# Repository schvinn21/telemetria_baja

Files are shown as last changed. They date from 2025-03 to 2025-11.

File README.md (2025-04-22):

# 📡 Projeto de Telemetria CAN com ESP32

Este projeto realiza a leitura de dados do acelerômetro MPU6050 e do módulo GPS NEO-M8N, transmitindo-os via protocolo CAN utilizando dois ESP32 e módulos com CI SN65HVD230. O objetivo é facilitar a coleta de dados em tempo real em ambientes como veículos off-road (ex: Baja SAE).

---

## 📁 Estrutura de Diretórios Recomendada

```bash
project-name/
├── CMakeLists.txt
├── sdkconfig
├── sdkconfig.defaults
├── main/
│   ├── main.c
│   └── CMakeLists.txt
├── components/
│   ├── mpu6050/
│   │   ├── mpu6050.c
│   │   ├── mpu6050.h
│   │   └── CMakeLists.txt
│   ├── gps/
│   │   ├── gps.c
│   │   ├── gps.h
│   │   └── CMakeLists.txt
│   └── can_transmiter/
│       ├── can_transmiter.c
│       ├── can_transmiter.h
│       └── CMakeLists.txt
├── .gitignore
└── README.md
```

> ❗ **Atenção:** A pasta `build/` gerada na compilação não deve ser versionada. Certifique-se de incluí-la no `.gitignore`.

---

## 💻 Requisitos para Execução

### 🧰 Instalações Necessárias

1. [ESP-IDF](https://docs.espressif.com/projects/esp-idf/en/latest/esp32/get-started/index.html)
2. Python 3 (recomendado usar virtualenv)
3. Dependências via pip:
   ```bash
   pip install esptool pyserial
   ```

### 📦 Drivers (Windows)

- Driver USB-to-Serial para ESP32 (CH340 ou CP2102)

---

## 🛠️ Como Compilar e Rodar

1. Configure o ambiente:
   ```bash
   . $HOME/esp/esp-idf/export.sh
   ```

2. Navegue até o diretório do projeto:
   ```bash
   cd project-name
   ```

3. Compile e carregue:
   ```bash
   idf.py build
   idf.py -p /dev/ttyUSB0 flash monitor
   ```

---

## 🚐 Funcionamento da Comunicação CAN

A rede CAN (Controller Area Network) é utilizada para comunicação entre microcontroladores, permitindo troca de dados em tempo real, com alta confiabilidade e resistência a ruído.

### ✅ Características:

- Comunicação serial diferencial (alta imunidade a interferências)
- Taxa usada: **500 kbps**
- Até **8 bytes por frame CAN**
- Prioridade de mensagens baseada no ID (menor ID = maior prioridade)

### 🔧 Aplicação neste Projeto:

Dois ESP32 comunicam-se via CAN:

- O **Transmissor** envia dados do MPU6050 e GPS usando dois frames:
  - `ID 0x123`: Aceleração X, Y, Z
  - `ID 0x124`: Latitude e Longitude (tipo `float`, codificados em IEEE 754)

- O **Receptor** decodifica os frames recebidos e imprime os valores no terminal.

> ⚠️ Os módulos CAN (SN65HVD230) devem ser ligados com resistores de terminação de 120 Ω entre CAN_H e CAN_L.

---

## 📌 Observações

- O GPS deve estar em ambiente aberto para obter sinal.
- Certifique-se de alimentar corretamente os módulos. O GPS e o CAN podem exigir corrente acima de 100 mA.
- Evite subir arquivos como `build/` e `.pioenvs/` ao repositório. Use `.gitignore` corretamente.

---

## 📷 Exemplo de Saída

```
Accel X: -520, Y: 256, Z: 16234
Latitude: -30.0457
Longitude: -51.2309
```

---

## 📍 Próximos Passos

- Envio dos dados via rede GSM (SIM900A)
- Visualização em dashboard web
- Armazenamento local (SD Card) ou remoto (MQTT, REST API)

---

Desenvolvido por **Eduardo Schvinn**  
Projeto para aplicação em competições **Baja SAE** 🏁

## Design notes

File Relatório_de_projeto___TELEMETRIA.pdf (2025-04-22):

# Documentação do Projeto de Telemetria CAN com ESP32

### Eduardo Schvinn

### April 22, 2025

## 1 Introdução

Este projeto tem como objetivo transmitir dados de sensores (aceleração e GPS) via protocolo CAN utilizando ESP32. A proposta visa facilitar a coleta de dados em tempo real para aplicações como monitoramento veicular em protótipos Baja SAE.

## 2 Componentes Utilizados

- 2 x ESP32 (ESP-IDF)
- 1 x Módulo MPU6050 (Acelerômetro e Giroscópio)
- 1 x Módulo GPS NEO-M8N
- 2 x Módulo CAN com CI SN65HVD230
- Cabos, protoboards e fonte de alimentação

## 3 Funcionamento Geral

- O ESP transmissor coleta dados do MPU6050 e do GPS.
- As informações são organizadas em pacotes CAN com identificadores 0x123 (aceleração) e 0x124 (GPS).
- O ESP receptor interpreta os pacotes e exibe os dados no terminal.

## 4 Estrutura dos Frames CAN Transmitidos

O sistema transmite dois frames distintos na rede CAN, cada um com identificador e estrutura de payload definidos:

### Frame 1: Dados de Aceleração (ID 0x123)

- 6 bytes no total.
- Cada componente da aceleração (X, Y, Z) codificado em dois bytes (int16 t).
- Formato big-endian:

[ ax H, ax L, ay H, ay L, az H, az L ]

- Exemplo:

– ax = -512 0xFE00, ay = 256 0x0100, az = 16383 0x3FFF

– Payload: FE 00 01 00 3F FF

### Frame 2: Coordenadas GPS (ID 0x124)

- 8 bytes no total.
- Latitude e longitude como float (IEEE 754), 4 bytes cada.
- Formato little-endian:

[ latitude (4B), longitude (4B) ]

- Exemplo:

– Latitude = -30.0457, Longitude = -51.2309

– Representação: 9A 99 F0 C1 0B 8D 4E C2

### Resumo dos Frames

Frame | ID | Bytes (Payload) | Conteúdo
Frame 1 Frame 2 | 0x123 0x124 | 6 8 | Aceleração (X, Y, Z) Latitude (4B) + Longitude (4B)

## 5 Formato dos Dados Transmitidos

A separação em dois frames evita a perda de precisão das coordenadas GPS. Frame 1 (ID 0x123):

- Bytes 0-1: aceleração em X (int16)
- Bytes 2-3: aceleração em Y (int16)
- Bytes 4-5: aceleração em Z (int16)

Frame 2 (ID 0x124):

- Bytes 0-3: latitude (float)
- Bytes 4-7: longitude (float)

## 6 Conversão de Dados GPS no Receptor

A transmissão das coordenadas GPS segue o padrão IEEE 754 para float (4 bytes), utilizando a ordem little-endian.

### No Transmissor

Os valores são copiados diretamente para o buffer da mensagem:

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

### No Receptor

O processo reverso reconstitui os valores:

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

### Considerações

- A ordem dos bytes deve ser idêntica em ambos os dispositivos.
- O uso de memcpy garante fidelidade dos dados sem conversões.
- O formato binário permite transmitir floats com eficiência.

## 7 Fluxo do Sistema

1. Inicialização de UART (GPS), I2C (MPU6050) e CAN.
2. Leitura dos sensores.
3. Transmissão a cada 500ms.
4. Receptor interpreta e exibe os dados no terminal.

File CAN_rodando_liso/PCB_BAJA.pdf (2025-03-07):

1 | Placas de Circuito Impresso – CTJ Baja

SENSOR DE TEMPERATURA

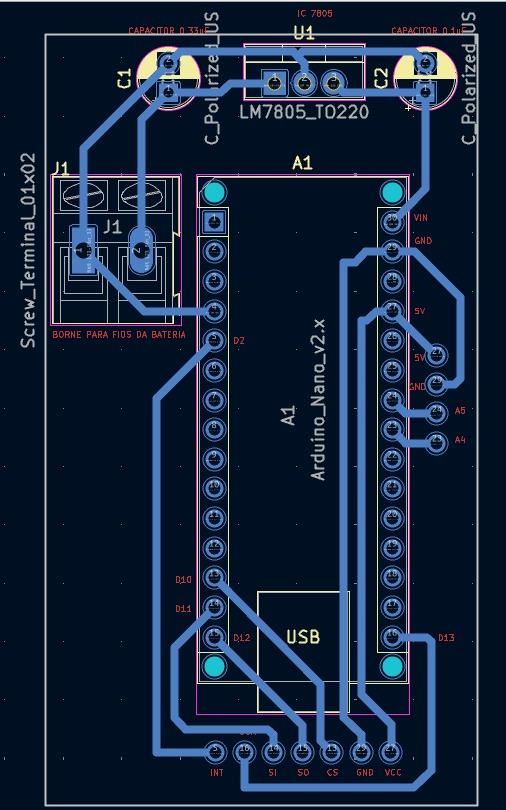
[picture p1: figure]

COMPONENTES

- Arduino nano;
- Dois capacitores;
- Um regulador de tensão LM7805;
- Módulo CAN MCP2515;
- Sensor de temperatura mlx90614

PINAGEM

1. Módulo CAN → Arduino Nano
- Int → D2
- SCK →D13
- SI → D11
- SO → D12
- CS → D10
- GND → GND
- VCC → 5V
2. Sensor temp. → Arduino nano
- VIN →5V
- GND → GND
- SCL → A5
- SDA → A4

SENSOR DE COMBUSTÍVEL

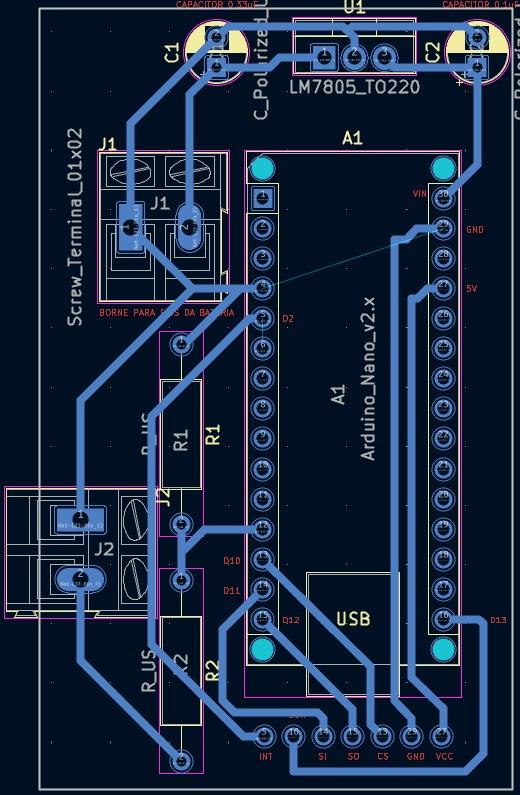
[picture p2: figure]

COMPONENTES

- Arduino nano;
- Dois capacitores;
- Um regulador de tensão LM7805;
- Módulo CAN MCP2515;
- Divisor de tensão (dois resistores);
- Sensor de combustível.

PINAGEM

1. Módulo CAN → Arduino Nano
- Int → D2
- SCK →D13
- SI → D11
- SO → D12
- CS → D10
- GND → GND
- VCC → 5V
2. Sensor combustível → Arduino nano
- Sinal → R2 → D9 → R1

R1 → GND

- GND → GND

SENSOR DE VELOCIDADE

COMPONENTES

- Arduino nano;

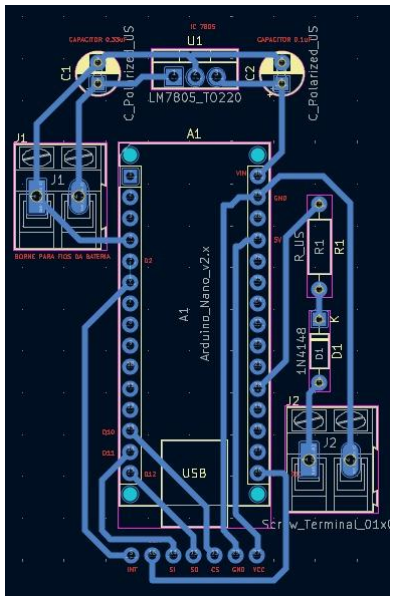
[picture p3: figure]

- Dois capacitores;
- Um regulador de tensão LM7805;
- Módulo CAN MCP2515;
- Resistor;
- Diodo;
- Sensor de velocidade;

PINAGEM

1. Módulo CAN → Arduino Nano
- Int → D2
- SCK →D13
- SI → D11
- SO → D12
- CS → D10
- GND → GND
- VCC → 5V
2. Sensor de Velocidade → Arduino nano
- GND → GND
- Sinal → diodo → resistor → A1

ESP32

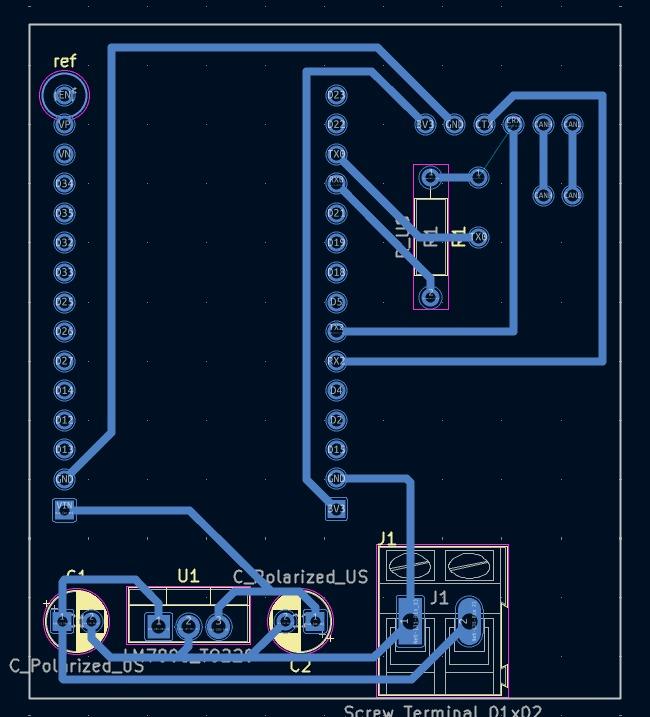
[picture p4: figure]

COMPONENTES

- ESP32;
- Dois capacitores;
- Um regulador de tensão LM7805;
- Módulo CAN bus SN65HVD230;
- Resistor.

PINAGEM

1. Módulo CAN → ESP32
- 3V3 → 3V3
- GND →GND
- CTX → RX2
- CRX → TX2
- CANH → CANH
- CANL → CANL
2. ESP32 COMUNICAÇÃO → UART
- RX0 → resistor → TX1 (Arduino)
- TX0 → RX0 (Arduino)

PAINEL

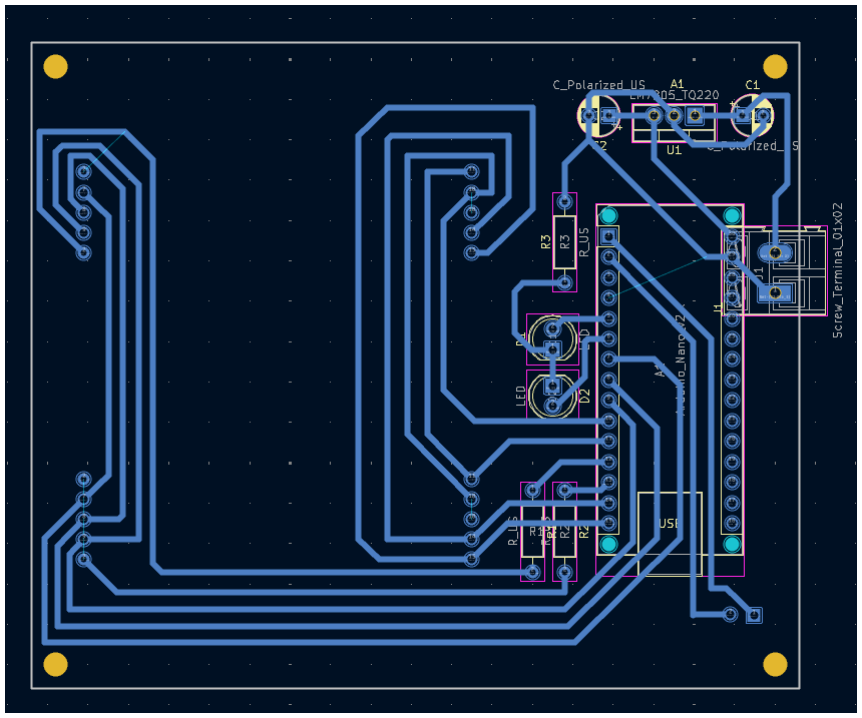
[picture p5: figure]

COMPONENTES

- Arduino nano;
- Dois capacitores;
- Um regulador de tensão LM7805;
- Três resistores;
- Dois displays de 7 segmentos, cátodo comum, FJS18101AH;
- Dois LEDs;
- Dois furos para comunicação UART;

PINAGEM

Os dois displays estão com todos os pinos conectados, exceto os pinos 1, 5 e 8

1. Displays → Arduino
- Disp.(1) 5 → Resistor 1 → D9
- Disp.(2) 5 → Resistor 2 → D10
- 7 → D11 > A
- 6 → D12 > B
- 4 → D6 > C
- 3 → D5 > D
- 2 → D4 > E
- 9 → D7 > F
- 10 → D8 > G
- 8 → Não está conectado > DP
2. LEDs → Arduino
- LED(1) → D2
- GND → GND led(2) → resistor → GND
- LED(2) → D3
- GND → GND led(1) → resistor → GND
3. Comunicação UART_ESP32 → Arduino
- RX0 → TX1
- TX0 → resistor(esp32) → RX0

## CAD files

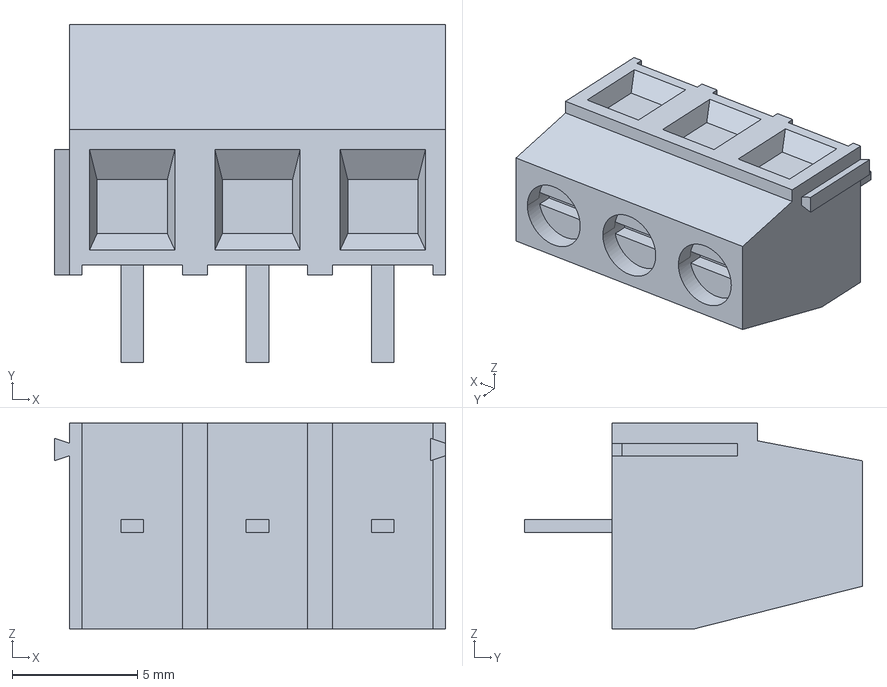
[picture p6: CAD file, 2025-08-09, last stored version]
pcb_telemetria/componentes/282836-3/282836-3.step
15.6 x 13.5 x 8.20 mm

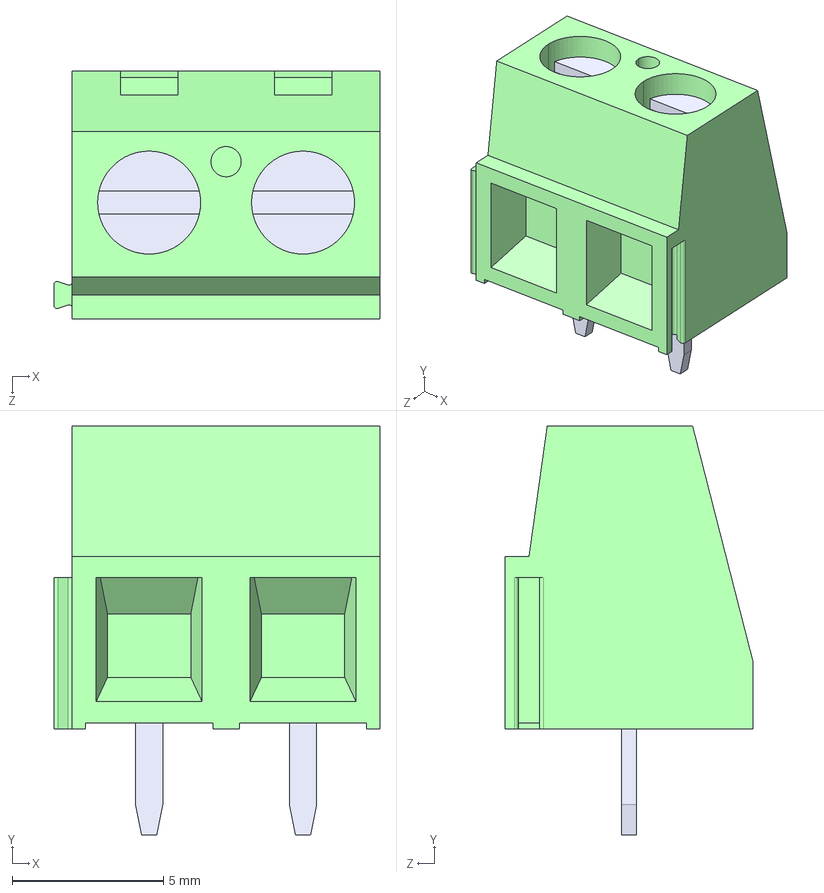
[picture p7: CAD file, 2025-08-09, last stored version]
pcb_telemetria/componentes/282837-2/282837-2.step
10.8 x 13.5 x 8.20 mm

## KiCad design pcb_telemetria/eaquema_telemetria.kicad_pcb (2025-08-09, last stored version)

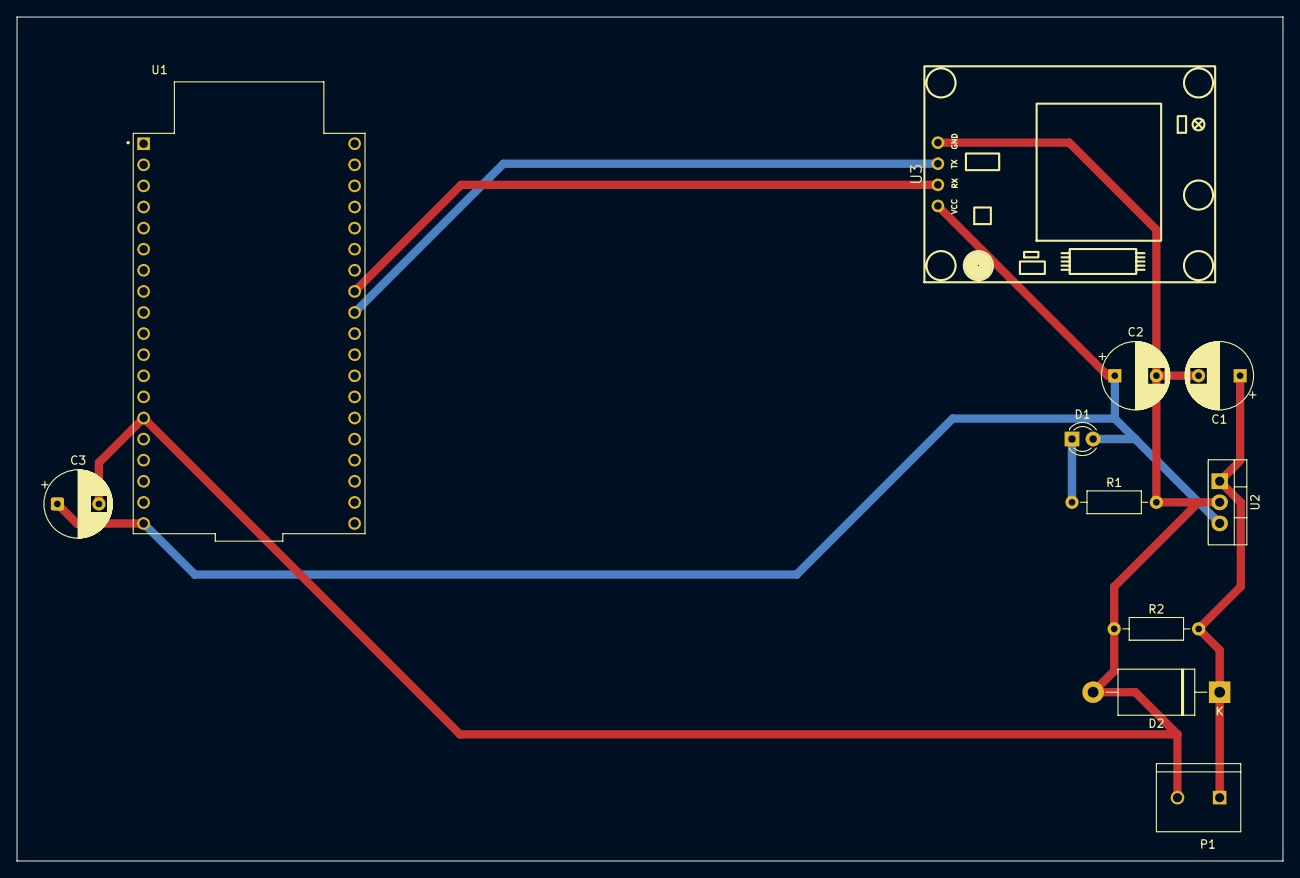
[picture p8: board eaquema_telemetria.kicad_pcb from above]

Board: 2 copper layers, 152.4 x 101.6 mm, 11 parts (0 on the bottom side), 6 nets.

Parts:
C1: 220uF; CP_Radial_D8.0mm_P5.00mm
C2, C3: 10nF; CP_Radial_D8.0mm_P5.00mm
D1: LED; LED_D3.0mm
D2: 1N4742; D_DO-201AE_P15.24mm_Horizontal
P1: kre; TE_282837-2
R1: 220; R_Axial_DIN0207_L6.3mm_D2.5mm_P10.16mm_Horizontal
R2: 2.2; R_Axial_DIN0207_L6.3mm_D2.5mm_P10.16mm_Horizontal
U1: ESP32-DEVKITC; MODULE_ESP32-DEVKITC
U2: LM7805_TO220; TO-220-3_Vertical
U3: NEO6MV2; NEO-6M-V2-GPSMODULE-FOOTPRINT

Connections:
+5V: C2.1, C3.1, D1.2 (A), U1.19 (EXT_5V), U2.3 (VO), U3.1 (VCC)
+12V: C1.1, D2.1 (A1), P1.1, R2.2, U2.1 (VI)
GND: C1.2, C2.2, C3.2, D2.2 (A2), P1.2, R1.2, R2.1, U1.14 (GND1), U2.2 (GND), U3.4 (GND)
unnamed: D1.1 (K), R1.1
RX: U1.31 (IO19), U3.2 (RX)
TX: U1.30 (IO18), U3.3 (TX)

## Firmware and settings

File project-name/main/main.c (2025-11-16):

// #include <stdio.h>
// #include <inttypes.h>              // PRIu32
// #include "freertos/FreeRTOS.h"
// #include "freertos/task.h"
// #include "esp_log.h"

// #include "sensor_temp.h"           // driver DS18B20
// #include "sensor_fluxo.h"          // driver de fluxo
// #include "can_transmiter.h"        // seu driver CAN

// static const char *TAG = "app_main";

// // Pinos escolhidos
// #define DS18_PIN    GPIO_NUM_4     // DS18B20 no GPIO4
// #define FLUXO_PIN   GPIO_NUM_14    // Sensor de fluxo no GPIO14

// void app_main(void)
// {
//     esp_err_t err;

//     vTaskDelay(pdMS_TO_TICKS(100));   // pequena estabilização

//     // ---------- LOG DO DRIVER GPIO MAIS BAIXO (pra não poluir serial) ----------
//     esp_log_level_set("gpio", ESP_LOG_WARN);

//     // ---------- CONFIG DS18B20 ----------
//     ds18b20_t temp1;

//     err = ds18b20_init(&temp1, DS18_PIN, false);   // VDD em 3V3, sem modo parasita
//     if (err != ESP_OK) {
//         ESP_LOGE(TAG, "DS18B20 init falhou: %s", esp_err_to_name(err));
//         return;
//     }

//     (void) ds18b20_set_resolution(&temp1, 12);     // 12 bits (~750 ms conversão)

//     // ---------- CONFIG FLUXO ----------
//     sensor_fluxo_config_t cfg = {
//         .pin               = FLUXO_PIN,
//         .pulses_per_liter  = 450.0f,   // ajusta pro seu sensor
//         .sample_ms         = 1000,     // janela de cálculo (ms)
//         .glitch_us         = 100,      // anti-ruído (us)
//         .use_internal_pullup = true    // ideal ter pull-up externo de 10k em 3V3 também
//     };

//     err = sensor_fluxo_init(&cfg);
//     if (err != ESP_OK) {
//         ESP_LOGE(TAG, "sensor_fluxo_init falhou: %s", esp_err_to_name(err));
//         return;
//     }

//     // ---------- CONFIG CAN ----------
//     err = can_transmiter_init();
//     if (err != ESP_OK) {
//         ESP_LOGE(TAG, "CAN init falhou: %s", esp_err_to_name(err));
//         return;
//     }

//     ESP_LOGI(TAG, "Sistema iniciado: CSV pela serial + envio via CAN...");

//     // --------- CABEÇALHO CSV (uma vez só) ---------
//     // Formato: temp_c;flow_l_min;total_liters;pulses_window
//     printf("temp_c;flow_l_min;total_liters;pulses_window\r\n");
//     fflush(stdout);

//     while (1) {
//         float t1 = 0.0f;
//         sensor_fluxo_metrics_t m = (sensor_fluxo_metrics_t){0};

//         // --------- TEMPERATURA ---------
//         if (ds18b20_read_celsius(&temp1, &t1) != ESP_OK) {
//             ESP_LOGW(TAG, "falha ao ler temp1");
//             t1 = -999.0f;  // marca erro no CSV
//         }

//         // --------- FLUXO ---------
//         sensor_fluxo_get_metrics(&m);
// dgbd
//         // --------- LINHA CSV PARA PYTHON ---------
//         printf("%.2f;%.3f;%.3f;%" PRIu32 "\r\n",
//                t1,
//                (double)m.flow_l_min,
//                (double)m.total_liters,
//                m.pulses_window);
//         fflush(stdout);

//         // --------- ENVIO POR CAN ---------
//         // temp2 por enquanto = temp1 (até você ligar um segundo DS18)
//         float temp2 = t1;
//         err = can_enviar_temp_e_total_compacto(t1, temp2, m.total_liters);
//         if (err != ESP_OK) {
//             ESP_LOGW(TAG, "Falha ao enviar quadro CAN");
//         }

//         // Log básico local
//         ESP_LOGI(TAG, "T=%.2f °C | flow=%.3f L/min | total=%.3f L",
//                  t1, (double)m.flow_l_min, (double)m.total_liters);

//         vTaskDelay(pdMS_TO_TICKS(1000));  // 1 amostra / frame por segundo
//     }
// }




// #include <stdio.h>
// #include <inttypes.h>              // PRIu32
// #include "freertos/FreeRTOS.h"
// #include "freertos/task.h"
// #include "esp_log.h"

// #include "sensor_temp.h"           // driver DS18B20
// #include "sensor_fluxo.h"          // driver de fluxo

// static const char *TAG = "app_main";

// // Pinos escolhidos
// #define DS18_PIN    GPIO_NUM_4     // DS18B20 no GPIO4
// #define FLUXO_PIN   GPIO_NUM_14    // Sensor de fluxo no GPIO14

// void app_main(void)
// {
//     esp_err_t err;

//     vTaskDelay(pdMS_TO_TICKS(100));   // pequena estabilização

//     // ---------- CONFIG DS18B20 ----------
//     ds18b20_t temp1;

//     err = ds18b20_init(&temp1, DS18_PIN, false);   // VDD em 3V3, sem modo parasita
//     if (err != ESP_OK) {
//         ESP_LOGE(TAG, "DS18B20 init falhou: %s", esp_err_to_name(err));
//         return;
//     }

//     (void) ds18b20_set_resolution(&temp1, 12);     // 12 bits (~750 ms conversão)

//     // ---------- CONFIG FLUXO (igual teu exemplo) ----------
//     sensor_fluxo_config_t cfg = {
//         .pin               = FLUXO_PIN,
//         .pulses_per_liter  = 450.0f,   // ajusta pro seu sensor
//         .sample_ms         = 1000,     // janela de cálculo (ms)
//         .glitch_us         = 100,      // anti-ruído (us)
//         .use_internal_pullup = true    // ideal ter pull-up externo de 10k em 3V3 também
//     };

//     err = sensor_fluxo_init(&cfg);
//     if (err != ESP_OK) {
//         ESP_LOGE(TAG, "sensor_fluxo_init falhou: %s", esp_err_to_name(err));
//         return;
//     }

//     ESP_LOGI(TAG, "Sistema iniciado: lendo temperatura (GPIO4) e fluxo (GPIO14)...");

//     while (1) {
//         float t1 = 0.0f;
//         sensor_fluxo_metrics_t m = {0};

//         // --------- TEMPERATURA ---------
//         if (ds18b20_read_celsius(&temp1, &t1) != ESP_OK) {
//             ESP_LOGW(TAG, "falha ao ler temp1");
//         }

//         // --------- FLUXO ---------
//         sensor_fluxo_get_metrics(&m);

//         ESP_LOGI(TAG,
//                  "T=%.2f °C | pulses=%" PRIu32 " | flow=%.3f L/min | total=%.3f L",
//                  t1,
//                  m.pulses_window,
//                  (double)m.flow_l_min,
//                  (double)m.total_liters);

//         vTaskDelay(pdMS_TO_TICKS(1000));
//     }
// }


#include <stdio.h>
#include <inttypes.h>
#include "freertos/FreeRTOS.h"
#include "freertos/task.h"
#include "rotacao.h"
#include "esp_log.h"
#include "esp_err.h"

static const char *TAG = "app";

// === Ajustes do projeto ===
#define RPM_PIN             GPIO_NUM_27   // escolha um GPIO "seguro" para entrada
#define PULSES_PER_REV      2             // nº de pulsos por volta mecânica
#define MIN_PULSE_US        500        // anti-ruído: rejeita bordas mais rápidas que isso
#define SAMPLE_WINDOW_MS    1000          // janela de amostragem p/ cálculo de RPM

// === Parâmetros do filtro exponencial ===
#define RPM_FILTER_ALPHA    0.20f         // 0.1 = mais suave; 0.5 = mais responsivo

void rpm_task(void *arg)
{
    rpm_counter_t *rc = (rpm_counter_t*)arg;

    // estado do filtro
    static float rpm_filt = 0.0f;
    static bool  filt_init = false;

    ESP_LOGI(TAG, "rpm_task iniciada, janela=%d ms, pulses/rev=%u",
             SAMPLE_WINDOW_MS, rc->cfg.pulses_per_rev);

    while (1) {
        vTaskDelay(pdMS_TO_TICKS(SAMPLE_WINDOW_MS));

        uint32_t pulses = rpm_counter_read_and_reset(rc);
        uint32_t rpm    = rpm_counter_to_rpm(pulses, SAMPLE_WINDOW_MS,
                                             rc->cfg.pulses_per_rev);

        // inicializa filtro com primeira medida
        if (!filt_init) {
            rpm_filt = (float)rpm;
            filt_init = true;
        } else {
            rpm_filt = RPM_FILTER_ALPHA * (float)rpm
                     + (1.0f - RPM_FILTER_ALPHA) * rpm_filt;
        }

        // 1) Linha "limpa" para o Python: RAW;FILT
        //    Ex.: 1234;1180.5
        printf("%" PRIu32 ";%.1f\n", rpm, (double)rpm_filt);

        // 2) Log informativo no monitor
        ESP_LOGI(TAG, "RPM raw=%" PRIu32 " | RPM filt=%.1f (pulses=%" PRIu32 ")",
                 rpm, (double)rpm_filt, pulses);
    }
}

void app_main(void)
{
    ESP_LOGI(TAG, "Iniciando leitura de RPM...");

    rpm_counter_t rc;
    rpm_counter_cfg_t cfg = {
        .pin            = RPM_PIN,
        .pulses_per_rev = PULSES_PER_REV,
        .min_pulse_us   = MIN_PULSE_US,
        .pullup         = true,     // habilita PULLUP interno
        .rising_edge    = true
    };

    esp_err_t err = rpm_counter_init(&rc, &cfg);
    if (err != ESP_OK) {
        ESP_LOGE(TAG, "Falha em rpm_counter_init(): %s", esp_err_to_name(err));
        return;
    }
    ESP_LOGI(TAG, "rpm_counter_init OK");

    err = rpm_counter_start(&rc);
    if (err != ESP_OK) {
        ESP_LOGE(TAG, "Falha em rpm_counter_start(): %s", esp_err_to_name(err));
        return;
    }
    ESP_LOGI(TAG, "rpm_counter_start OK");

    if (xTaskCreatePinnedToCore(rpm_task,
                                "rpm_task",
                                4096,      // mais stack pra garantir
                                &rc,
                                5,
                                NULL,
                                tskNO_AFFINITY) != pdPASS) {
        ESP_LOGE(TAG, "Falha ao criar tarefa RPM");
        return;
    }

    ESP_LOGI(TAG, "Tarefa RPM criada com sucesso");
    // app_main pode retornar; rpm_task continua rodando
}

// #include <stdio.h>
// #include "freertos/FreeRTOS.h"
// #include "freertos/task.h"
// #include "esp_log.h"

// #include "sensor_temp.h"       // DS18B20
// #include "sensor_fluxo.h"      // teu driver já funcional
// #include "can_transmiter.h"    // abaixo

// #define TAG "APP"

// // dois sensores de temp
// #define DS18_PIN_1  GPIO_NUM_33
// #define DS18_PIN_2  GPIO_NUM_32
// void app_main(void)
// {
//     esp_err_t err;

//     vTaskDelay(pdMS_TO_TICKS(100));

//     // ---------- TEMPERATURA ----------
//     ds18b20_t temp1;
//     ds18b20_t temp2;

//     err = ds18b20_init(&temp1, DS18_PIN_1, false);
//     if (err != ESP_OK) {
//         ESP_LOGE(TAG, "DS18B20 #1 init falhou: %s", esp_err_to_name(err));
//         return;
//     }

//     err = ds18b20_init(&temp2, DS18_PIN_2, false);
//     if (err != ESP_OK) {
//         ESP_LOGE(TAG, "DS18B20 #2 init falhou: %s", esp_err_to_name(err));
//         return;
//     }

//     (void) ds18b20_set_resolution(&temp1, 12);
//     (void) ds18b20_set_resolution(&temp2, 12);

//     // ---------- FLUXO (só quero o total) ----------
//     sensor_fluxo_config_t fcfg = {
//         .pin                 = GPIO_NUM_35,   // AJUSTA
//         .pulses_per_liter    = 450.0f,       // AJUSTA
//         .sample_ms           = 1000,
//         .glitch_us           = 100,
//         .use_internal_pullup = true
//     };

//     err = sensor_fluxo_init(&fcfg);
//     if (err != ESP_OK) {
//         ESP_LOGE(TAG, "sensor_fluxo_init falhou: %s", esp_err_to_name(err));
//         return;
//     }

//     // ---------- CAN ----------
//     err = can_transmiter_init();
//     if (err != ESP_OK) {
//         ESP_LOGE(TAG, "CAN init falhou: %s", esp_err_to_name(err));
//         return;
//     }

//     ESP_LOGI(TAG, "Sistema iniciado. Enviando 2x temp + total_liters via CAN...");

//     while (1) {
//         float t1 = 0.0f;
//         float t2 = 0.0f;
//         sensor_fluxo_metrics_t m = {0};

//         // temperaturas
//         if (ds18b20_read_celsius(&temp1, &t1) != ESP_OK) {
//             ESP_LOGW(TAG, "falha ler temp1");
//         }
//         if (ds18b20_read_celsius(&temp2, &t2) != ESP_OK) {
//             ESP_LOGW(TAG, "falha ler temp2");
//         }

//         // fluxo (mas vou usar só o total)
//         sensor_fluxo_get_metrics(&m);

//         ESP_LOGI(TAG,
//                  "T1=%.2f °C | T2=%.2f °C | total=%.3f L",
//                  t1, t2, (double)m.total_liters);

//         // 1) envia temperaturas
//         // can_enviar_temp_e_total_compacto(t1, t2, m.total_liters);

//         vTaskDelay(pdMS_TO_TICKS(1000));
//     }
// }





// #include <stdio.h>
// #include "freertos/FreeRTOS.h"
// #include "freertos/task.h"
// #include "mpu6050.h"
// #include "gps.h"
// #include "can_transmiter.h"  // nome correto
// #include "sensor_temp.h"
// #include "esp_log.h"


// extern float gps_latitude;
// extern float gps_longitude;

// void app_main(void) {
//     printf("Iniciando sensores...\n");
    
//     ds18b20_t sensor;
//     ESP_ERROR_CHECK(ds18b20_init(&sensor, GPIO_NUM_4, false)); // DQ no GPIO4
//     // opcional: ESP_ERROR_CHECK(ds18b20_set_resolution(&sensor, 12));

//     // if (mpu6050_init() != ESP_OK) {
//     //     printf("Falha ao inicializar o MPU6050\n");
//     //     return;
//     // }

//     // gps_init();
//     // gps_start_task();

//     // if (can_transmiter_init() != ESP_OK) {
//     //     printf("Falha ao inicializar CAN\n");
//     //     return;
//     // }

//     while (1) {
//         float t = 0.0f;
//         esp_err_t err = ds18b20_read_temperature(&sensor, &t);
//         if (err == ESP_OK) {
//             ESP_LOGI("APP", "Temperatura: %.2f °C", t);
//         } else {
//             ESP_LOGE("APP", "Falha ao ler temperatura (%s)", esp_err_to_name(err));
//         }
//         vTaskDelay(pdMS_TO_TICKS(1000));
//         // int16_t ax, ay, az;
//         // if (mpu6050_read_accel(&ax, &ay, &az) == ESP_OK) {
//         //     printf("Accel X: %d, Y: %d, Z: %d\n", ax, ay, az);
//         //     printf("Latitude: %.6f, Longitude: %.6f\n", gps_latitude, gps_longitude);
//         //     can_enviar_dados(ax, ay, az, gps_latitude, gps_longitude);
//         // } else {
//         //     printf("Erro na leitura do MPU6050\n");
//         // }
//         // vTaskDelay(pdMS_TO_TICKS(500));
//     }
// }


// #include "sensor_temp.h"
// #include "esp_log.h"
// #include "freertos/FreeRTOS.h"
// #include "freertos/task.h"

// #define APP_TAG   "APP"
// #define DS18_PIN  GPIO_NUM_33  // já está OK no seu hardware

// void app_main(void) {
//     vTaskDelay(pdMS_TO_TICKS(100)); // estabiliza

//     ds18b20_t sensor;
//     esp_err_t err = ds18b20_init(&sensor, DS18_PIN, false); // VDD=3V3 (sem parasita)
//     if (err != ESP_OK) {
//         ESP_LOGE(APP_TAG, "init falhou: %s", esp_err_to_name(err));
//         return;
//     }

//     // opcional: define resolução (12 bits = 750 ms)
//     err = ds18b20_set_resolution(&sensor, 12);
//     if (err != ESP_OK) {
//         ESP_LOGW(APP_TAG, "nao consegui setar resolucao: %s (seguindo default)", esp_err_to_name(err));
//     }

//     while (1) {
//         float c = 0.0f;
//         err = ds18b20_read_celsius(&sensor, &c);
//         if (err == ESP_OK) {
//             ESP_LOGI(APP_TAG, "Temperatura: %.2f °C", c);
//         } else {
//             ESP_LOGE(APP_TAG, "Falha ao ler temperatura (%s)", esp_err_to_name(err));
//         }
//         vTaskDelay(pdMS_TO_TICKS(1000));
//     }
// }
// #include <stdio.h>
// #include "sensor_temp.h"
// #include "esp_log.h"
// #include "freertos/FreeRTOS.h"
// #include "freertos/task.h"

// #define APP_TAG   "APP"
// #define DS18_PIN  GPIO_NUM_4   // ajuste conforme o pino real do seu hardware

// void app_main(void) {
//     vTaskDelay(pdMS_TO_TICKS(100)); // estabiliza o sistema

//     ds18b20_t sensor;
//     esp_err_t err = ds18b20_init(&sensor, DS18_PIN, false); // VDD = 3V3 (sem modo parasita)
//     // if (err != ESP_OK) {
//     //     ESP_LOGE(APP_TAG, "Falha na inicialização: %s", esp_err_to_name(err));
//     //     return;
//     // }

//     // Define resolução opcionalmente (12 bits = ~750 ms de conversão)
//     err = ds18b20_set_resolution(&sensor, 12);
//     if (err != ESP_OK) {
//         ESP_LOGW(APP_TAG, "Não consegui definir resolução: %s (seguindo padrão)", esp_err_to_name(err));
//     }

//     ESP_LOGI(APP_TAG, "Iniciando leitura contínua do sensor DS18B20...");

//     // === LOOP INFINITO DE LEITURA ===
//     while (1) {
//         float temperatura = 0.0f;
//         err = ds18b20_read_celsius(&sensor, &temperatura);

//         if (err == ESP_OK) {
//             ESP_LOGI(APP_TAG, "Temperatura: %.2f °C", temperatura);
//         } else {
//             ESP_LOGE(APP_TAG, "Falha ao ler temperatura (%s)", esp_err_to_name(err));
//         }

//         // Intervalo de 1 segundo entre leituras
//         vTaskDelay(pdMS_TO_TICKS(1000));
//     }
// }


// #include <stdio.h>
// #include <inttypes.h>              // <- para PRIu32
// #include "freertos/FreeRTOS.h"
// #include "freertos/task.h"
// #include "esp_log.h"
// #include "sensor_fluxo.h"

// static const char *TAG = "app_main";

// void app_main(void)
// {
//     sensor_fluxo_config_t cfg = {
//         .pin = GPIO_NUM_5,          // ajuste o pino
//         .pulses_per_liter = 450.0f,  // ajuste o PPL do seu sensor
//         .sample_ms = 1000,           // janela de cálculo (ms)
//         .glitch_us = 100,            // anti-ruído (us)
//         .use_internal_pullup = true  // ideal ter pull-up externo de 10k para 3V3 também
//     };

//     esp_err_t err = sensor_fluxo_init(&cfg);
//     if (err != ESP_OK) {
//         ESP_LOGI(TAG, "sensor_fluxo_init falhou: %s", esp_err_to_name(err));
//         return;
//     }

//     while (1) {
//         sensor_fluxo_metrics_t m;
//         sensor_fluxo_get_metrics(&m);

//         // pulses_window é uint32_t -> use PRIu32
//         ESP_LOGI(TAG, "pulses=%" PRIu32 " | flow=%.3f L/min | total=%.3f L",
//                  m.pulses_window, (double)m.flow_l_min, (double)m.total_liters);

//         vTaskDelay(pdMS_TO_TICKS(1000));
//     }
// }

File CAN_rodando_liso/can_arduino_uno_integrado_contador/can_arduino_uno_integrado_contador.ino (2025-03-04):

#include <SPI.h>
#include <ACAN2515.h>

// Definição dos pinos do MCP2515
static const byte MCP2515_SCK = 13; // SCK input of MCP2515
static const byte MCP2515_SI = 11;  // SI input of MCP2515
static const byte MCP2515_SO = 12;  // SO output of MCP2515
static const byte MCP2515_CS = 10;  // CS input of MCP2515
static const byte MCP2515_INT = 3;  // INT output of MCP2515

// Criando objeto da biblioteca ACAN2515
ACAN2515 can(MCP2515_CS, SPI, MCP2515_INT);

// Frequência do cristal do MCP2515 (verifique se é 8MHz ou 16MHz)
static const uint32_t QUARTZ_FREQUENCY = 8UL * 1000UL * 1000UL; // 8 MHz

// Taxa de transmissão da rede CAN
static const uint32_t CAN_BIT_RATE = 500UL * 1000UL; // 500 kbps

#define SENSOR_PIN 2  // Pino digital conectado ao sinal do sensor
volatile unsigned int contadorPulsos = 0;

// Configurações físicas da roda fônica
const float raioRoda = 0.3; // Raio da roda em metros (exemplo: 30 cm)
const unsigned int furosPorRevolucao = 1; // Número de furos por revolução da roda fônica

void setup() {
    // Configuração do sensor Hall
    pinMode(SENSOR_PIN, INPUT_PULLUP);  // Configura o pino com pull-up interno
    attachInterrupt(digitalPinToInterrupt(SENSOR_PIN), contarPulsos, FALLING); // Configura interrupção

    // Inicializa comunicação serial
    Serial.begin(115200);
    while (!Serial);

    Serial.println("Iniciando MCP2515...");

    // Inicializa SPI
    SPI.begin();

    // Configuração do MCP2515
    ACAN2515Settings settings(QUARTZ_FREQUENCY, CAN_BIT_RATE);
    settings.mRequestedMode = ACAN2515Settings::NormalMode; // Modo normal para comunicação real

    const uint32_t errorCode = can.begin(settings, [] { can.isr(); });

    if (errorCode == 0) {
        Serial.println("MCP2515 configurado com sucesso!");
    } else {
        Serial.print("Erro na configuração do MCP2515: 0x");
        Serial.println(errorCode, HEX);
        while (1);
    }

    Serial.println("Sistema iniciado.");
}

void loop() {
    // Atualiza a contagem de pulsos e calcula a velocidade a cada segundo
    static unsigned long ultimoTempo = 0;
    unsigned long tempoAtual = millis();

    if (tempoAtual - ultimoTempo >= 1000) {
        // Calcula a velocidade
        float circunferencia = 2 * 3.14159 * raioRoda; // Comprimento da circunferência
        float revolucoesPorSegundo = (float)contadorPulsos / furosPorRevolucao;
        float velocidade = revolucoesPorSegundo * circunferencia; // Velocidade em metros por segundo

        // Converte para km/h
        velocidade *= 3.6;

        // Cria uma mensagem CAN com a velocidade
        CANMessage frame;
        frame.id = 0x13; // ID da mensagem (ajuste conforme necessário)
        frame.len = 2;   // Número de bytes (2 bytes para a velocidade em km/h)
        frame.ext = false; // Mensagem padrão (não estendida)

        // Converte a velocidade para inteiro (multiplicado por 100 para preservar duas casas decimais)
        int16_t velocidadeInt = (int16_t)(velocidade * 100);

        // Preenche os dados da mensagem
        frame.data[0] = (velocidadeInt >> 8) & 0xFF; // Byte alto da velocidade
        frame.data[1] = velocidadeInt & 0xFF;        // Byte baixo da velocidade

        // Envia a mensagem CAN
        if (can.tryToSend(frame)) {
            Serial.print("Mensagem CAN enviada com velocidade: ");
            Serial.print(velocidade);
            Serial.println(" km/h");
        } else {
            Serial.println("Falha ao enviar mensagem CAN!");
        }

        // Reseta o contador de pulsos
        contadorPulsos = 0;
        ultimoTempo = tempoAtual;
    }
}

void contarPulsos() {
    contadorPulsos++; // Incrementa o contador de pulsos a cada interrupção
}

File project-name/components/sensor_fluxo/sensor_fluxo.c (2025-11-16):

    #include "sensor_fluxo.h"

    #include <stdatomic.h>
    #include <inttypes.h>              // para PRIu32

    #include "esp_err.h"
    #include "esp_log.h"
    #include "esp_timer.h"
    #include "driver/gpio.h"

    // FreeRTOS / port
    #include "freertos/FreeRTOS.h"
    #include "freertos/portmacro.h"

    static const char *TAG = "sensor_fluxo";

    static sensor_fluxo_config_t g_cfg;
    static esp_timer_handle_t    g_timer = NULL;

    // contador de pulsos (ISR incrementa)
    static _Atomic uint32_t      g_pulse_count = 0;
    // anti-glitch
    static uint64_t              g_last_edge_us = 0;

    // spinlock para proteger a struct de métricas
    static portMUX_TYPE          g_spin = portMUX_INITIALIZER_UNLOCKED;

    static sensor_fluxo_metrics_t g_metrics = {0};

    static void IRAM_ATTR isr_handler(void *arg) {
        uint64_t now = (uint64_t)esp_timer_get_time();
        if (now - g_last_edge_us > g_cfg.glitch_us) {
            atomic_fetch_add_explicit(&g_pulse_count, 1, memory_order_relaxed);
            g_last_edge_us = now;
        }
    }

    // Timer: roda a cada sample_ms e atualiza L/min / litros
    static void timer_cb(void *arg) {
        uint32_t pulses = atomic_exchange_explicit(&g_pulse_count, 0, memory_order_relaxed);
        uint64_t now_us = esp_timer_get_time();

        portENTER_CRITICAL(&g_spin);
        uint64_t prev_us = g_metrics.last_window_us;
        if (prev_us == 0) prev_us = now_us - (uint64_t)g_cfg.sample_ms * 1000ULL;
        g_metrics.last_window_us = now_us;
        g_metrics.pulses_window  = pulses;

        float liters_window = (g_cfg.pulses_per_liter > 0.f) ? (pulses / g_cfg.pulses_per_liter) : 0.f;
        float minutes = (float)(now_us - prev_us) / 60000000.0f; // us -> min
        g_metrics.flow_l_min = (minutes > 0.f) ? (liters_window / minutes) : 0.f;
        g_metrics.total_liters += liters_window;
        portEXIT_CRITICAL(&g_spin);
    }

    esp_err_t sensor_fluxo_init(const sensor_fluxo_config_t *cfg) {
        if (!cfg) {
            ESP_LOGI(TAG, "cfg nulo");
            return ESP_ERR_INVALID_ARG;
        }
        if (cfg->pin < 0) {
            ESP_LOGI(TAG, "pino invalido");
            return ESP_ERR_INVALID_ARG;
        }

        g_cfg = *cfg;

        // GPIO de entrada
        gpio_config_t io = {
            .pin_bit_mask = 1ULL << g_cfg.pin,
            .mode = GPIO_MODE_INPUT,
            .pull_up_en = g_cfg.use_internal_pullup ? GPIO_PULLUP_ENABLE : GPIO_PULLUP_DISABLE,
            .pull_down_en = GPIO_PULLDOWN_DISABLE,
            .intr_type = GPIO_INTR_NEGEDGE
        };
        esp_err_t err = gpio_config(&io);
        if (err != ESP_OK) {
            ESP_LOGI(TAG, "gpio_config falhou: %s", esp_err_to_name(err));
            return err;
        }

        // serviço de interrupção
        err = gpio_install_isr_service(0);
        if (err != ESP_OK && err != ESP_ERR_INVALID_STATE) {
            ESP_LOGI(TAG, "gpio_install_isr_service falhou: %s", esp_err_to_name(err));
            return err;
        }
        err = gpio_isr_handler_add(g_cfg.pin, isr_handler, NULL);
        if (err != ESP_OK) {
            ESP_LOGI(TAG, "gpio_isr_handler_add falhou: %s", esp_err_to_name(err));
            return err;
        }

        // timer periódico
        const esp_timer_create_args_t targs = {
            .callback = &timer_cb,
            .name = "sensor_fluxo_tmr"
        };
        err = esp_timer_create(&targs, &g_timer);
        if (err != ESP_OK) {
            ESP_LOGI(TAG, "esp_timer_create falhou: %s", esp_err_to_name(err));
            return err;
        }
        err = esp_timer_start_periodic(g_timer, (uint64_t)g_cfg.sample_ms * 1000ULL);
        if (err != ESP_OK) {
            ESP_LOGI(TAG, "esp_timer_start_periodic falhou: %s", esp_err_to_name(err));
            return err;
        }

        ESP_LOGI(TAG,
                "Init OK (pin=%d, PPL=%.2f, sample=%" PRIu32 " ms, glitch=%" PRIu32 " us, pullup=%d)",
                g_cfg.pin, (double)g_cfg.pulses_per_liter, g_cfg.sample_ms, g_cfg.glitch_us,
                g_cfg.use_internal_pullup);

        return ESP_OK;
    }

    esp_err_t sensor_fluxo_set_enabled(bool enabled) {
        if (!g_timer) {
            ESP_LOGI(TAG, "timer nao criado");
            return ESP_ERR_INVALID_STATE;
        }
        esp_err_t err;
        if (enabled) {
            err = esp_timer_start_periodic(g_timer, (uint64_t)g_cfg.sample_ms * 1000ULL);
            if (err != ESP_OK) ESP_LOGI(TAG, "esp_timer_start_periodic falhou: %s", esp_err_to_name(err));
        } else {
            err = esp_timer_stop(g_timer);
            if (err != ESP_OK) ESP_LOGI(TAG, "esp_timer_stop falhou: %s", esp_err_to_name(err));
        }
        return err;
    }

    void sensor_fluxo_reset_totals(void) {
        atomic_store_explicit(&g_pulse_count, 0, memory_order_relaxed);
        portENTER_CRITICAL(&g_spin);
        g_metrics.total_liters = 0.0;
        g_metrics.pulses_window = 0;
        g_metrics.flow_l_min = 0.0f;
        g_metrics.last_window_us = 0;
        portEXIT_CRITICAL(&g_spin);
    }

    void sensor_fluxo_get_metrics(sensor_fluxo_metrics_t *out) {
        if (!out) return;
        portENTER_CRITICAL(&g_spin);
        *out = g_metrics;
        portEXIT_CRITICAL(&g_spin);
    }

    uint32_t sensor_fluxo_get_pulse_count(void) {
        return atomic_load_explicit(&g_pulse_count, memory_order_relaxed);
    }

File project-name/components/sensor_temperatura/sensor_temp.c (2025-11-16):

#include "sensor_temp.h"
#include "esp_log.h"
#include "esp_rom_sys.h"
#include "freertos/FreeRTOS.h"
#include "freertos/task.h"

#define TAG "DS18B20"

// ---------- Timings (µs) — folgados/estáveis ----------
#define T_RESETL_US    480
#define T_PRESENCE_US  70
#define T_RESET_END    410

#define T_SLOT_US      70
#define T_W1_LOW       6
#define T_W0_LOW       60
#define T_R_INIT       6
#define T_R_SAMPLE     12   // amostra ~18us após início do slot

// ---------- Comandos ----------
#define CMD_SKIP_ROM          0xCC
#define CMD_CONVERT_T         0x44
#define CMD_READ_SCRATCHPAD   0xBE
#define CMD_WRITE_SCRATCHPAD  0x4E
#define CMD_COPY_SCRATCHPAD   0x48

#define SCRATCHPAD_LEN 9

// ---------- GPIO helpers (open-drain) ----------
static inline void ow_cfg_od(gpio_num_t pin) {
    gpio_config_t cfg = {
        .pin_bit_mask = (1ULL << pin),
        .mode         = GPIO_MODE_INPUT_OUTPUT_OD,
        .pull_up_en   = GPIO_PULLUP_ENABLE,   // ainda use o pull-up EXTERNO 4k7
        .pull_down_en = GPIO_PULLDOWN_DISABLE,
        .intr_type    = GPIO_INTR_DISABLE
    };
    gpio_config(&cfg);
}
static inline void ow_drive_low(gpio_num_t pin) { gpio_set_level(pin, 0); }
static inline void ow_release (gpio_num_t pin) { gpio_set_level(pin, 1); }

// ---------- 1-Wire low level ----------
static esp_err_t ow_reset(gpio_num_t pin) {
    ow_cfg_od(pin);
    ow_drive_low(pin);
    esp_rom_delay_us(T_RESETL_US);
    ow_release(pin);
    esp_rom_delay_us(T_PRESENCE_US);
    int presence = gpio_get_level(pin);  // 0 = presença
    esp_rom_delay_us(T_RESET_END + 5);
    return (presence == 0) ? ESP_OK : ESP_ERR_NOT_FOUND;
}

static void ow_write_bit(gpio_num_t pin, int bit) {
    if (bit) {
        ow_drive_low(pin);
        esp_rom_delay_us(T_W1_LOW);
        ow_release(pin);
        esp_rom_delay_us(T_SLOT_US - T_W1_LOW);
    } else {
        ow_drive_low(pin);
        esp_rom_delay_us(T_W0_LOW);
        ow_release(pin);
        esp_rom_delay_us(T_SLOT_US - T_W0_LOW);
    }
}

static int ow_read_bit(gpio_num_t pin) {
    ow_drive_low(pin);
    esp_rom_delay_us(T_R_INIT);
    ow_release(pin);
    esp_rom_delay_us(T_R_SAMPLE);
    int level = gpio_get_level(pin);
    uint32_t elapsed = T_R_INIT + T_R_SAMPLE;
    if (T_SLOT_US > elapsed) esp_rom_delay_us(T_SLOT_US - elapsed);
    return level ? 1 : 0;
}

static void ow_write_byte(gpio_num_t pin, uint8_t byte) {
    for (int i = 0; i < 8; ++i) {
        ow_write_bit(pin, (byte >> i) & 0x01);
    }
}

static uint8_t ow_read_byte(gpio_num_t pin) {
    uint8_t v = 0;
    for (int i = 0; i < 8; ++i) v |= (ow_read_bit(pin) << i);
    return v;
}

// ---------- CRC Dallas ----------
static uint8_t crc8_dallas(const uint8_t *data, int len) {
    uint8_t crc = 0;
    for (int i = 0; i < len; ++i) {
        uint8_t in = data[i];
        for (int b = 0; b < 8; ++b) {
            uint8_t mix = (crc ^ in) & 0x01;
            crc >>= 1;
            if (mix) crc ^= 0x8C;
            in >>= 1;
        }
    }
    return crc;
}

// ---------- Internos ----------
static int tconv_ms_from_cfg(uint8_t cfg) {
    switch ((cfg >> 5) & 0x03) { // R1:R0
        case 0: return 94;   //  9 bits
        case 1: return 188;  // 10 bits
        case 2: return 375;  // 11 bits
        default: return 750; // 12 bits
    }
}

static esp_err_t ds18b20_start_conversion(const ds18b20_t *dev) {
    if (dev->parasite_power) {
        // sem strong pull-up → não suportamos parasita
        return ESP_ERR_NOT_SUPPORTED;
    }

    // Inicia conversão
    esp_err_t err = ow_reset(dev->pin);
    if (err != ESP_OK) {
        ESP_LOGE(TAG, "reset antes de CONVERT_T falhou: %s", esp_err_to_name(err));
        return err;
    }
    ow_write_byte(dev->pin, CMD_SKIP_ROM);
    ow_write_byte(dev->pin, CMD_CONVERT_T);

    // Ler config para saber a resolução e esperar o tempo certo;
    // se falhar, espera 750ms (12 bits).
    err = ow_reset(dev->pin);
    if (err != ESP_OK) {
        vTaskDelay(pdMS_TO_TICKS(750 + 20));
        return ESP_OK;
    }
    ow_write_byte(dev->pin, CMD_SKIP_ROM);
    ow_write_byte(dev->pin, CMD_READ_SCRATCHPAD);
    uint8_t sp[SCRATCHPAD_LEN] = {0};
    for (int i = 0; i < SCRATCHPAD_LEN; ++i) sp[i] = ow_read_byte(dev->pin);

    int tconv = tconv_ms_from_cfg(sp[4]);
    vTaskDelay(pdMS_TO_TICKS(tconv + 20));
    return ESP_OK;
}

static esp_err_t ds18b20_read_scratchpad(const ds18b20_t *dev, uint8_t *buf9) {
    // Duas tentativas (ruído/clone)
    for (int attempt = 0; attempt < 2; ++attempt) {
        esp_err_t err = ow_reset(dev->pin);
        if (err != ESP_OK) return err;

        ow_write_byte(dev->pin, CMD_SKIP_ROM);
        ow_write_byte(dev->pin, CMD_READ_SCRATCHPAD);

        uint8_t sp[SCRATCHPAD_LEN];
        for (int i = 0; i < SCRATCHPAD_LEN; ++i) sp[i] = ow_read_byte(dev->pin);

        uint8_t crc = crc8_dallas(sp, 8);
        if (crc == sp[8]) {
            for (int i = 0; i < SCRATCHPAD_LEN; ++i) buf9[i] = sp[i];
            return ESP_OK;
        }
        esp_rom_delay_us(200);
    }
    return ESP_ERR_INVALID_CRC;
}

// ---------- API ----------
esp_err_t ds18b20_init(ds18b20_t *dev, gpio_num_t pin, bool parasite_power) {
    if (!dev) return ESP_ERR_INVALID_ARG;
    dev->pin = pin;
    dev->parasite_power = parasite_power;

    ow_cfg_od(pin);
    vTaskDelay(pdMS_TO_TICKS(10));

    esp_err_t err = ow_reset(pin);
    if (err != ESP_OK) {
        ESP_LOGE(TAG, "Sem presença no 1-Wire (verifique VDD=3V3, GND, DQ→GPIO e pull-up 4k7)");
        return err;
    }
    return ESP_OK;
}
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

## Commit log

2025-03-06 Create display
    Teste do display que o Leo fez.
2025-03-07 Add files via upload
    Documento com os componentes e as pinagens de cada PCB
2025-04-22 can_transmiter
    Código no qual faz a coleta dos dados de sensores e envia através da CAN.
2025-04-22 can_receiver
    Aqui é onde recebe os dados da CAN, e envia os dados para um servidor para exibição.
2025-08-09 Arquivos KICAD da pcb
    [282836-3.step, 282837-2.step, eaquema_telemetria.kicad_pcb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]
2025-10-15 Adição do sensor de temperatura
2025-11-16 código completo
    [dados_fluxo_temp_com_ruido.csv, dados_fluxo_temp_sem_ruido.csv, dados_rpm_com_filtrado.csv]
